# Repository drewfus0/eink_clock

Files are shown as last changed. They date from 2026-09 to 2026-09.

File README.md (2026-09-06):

# ESP32-E E-Paper Smart Clock & Environmental Monitor

<p align="center">
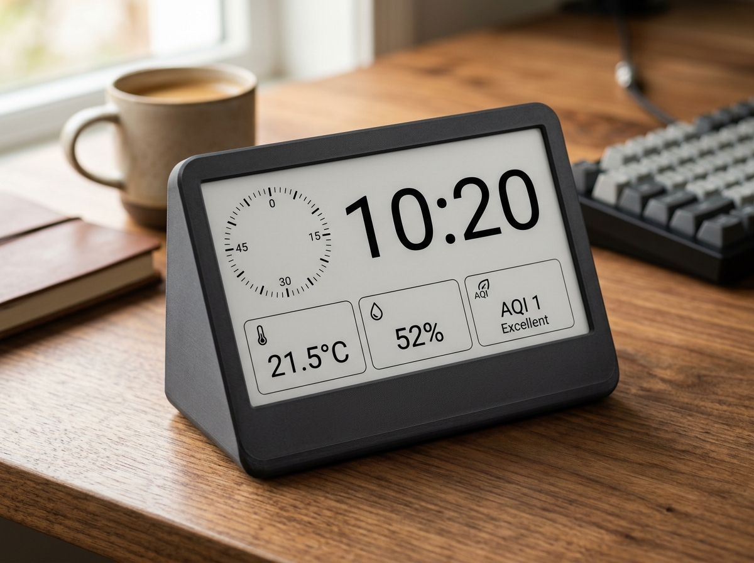
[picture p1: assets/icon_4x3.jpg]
ESP32-E E-Paper Clock
  
</p>

An ultra-low-power, battery-friendly smart desk clock and environmental monitor built with the **DFRobot FireBeetle 2 ESP32-E**, a **Waveshare 7.5" V2 (800x480) E-Paper display**, and an **ENS160 + AHT21 sensor module**.

Features automated **dual-mode Over-The-Air (OTA) updates** (GitHub Releases & local Web Browser), a fast 10-second circular seconds ring with differential refresh, and a custom **3D-printable 70° desk stand enclosure**.

---

## ✨ Features

- **High-Contrast 7.5" E-Paper Display (800x480)**:
  - Giant, crisp time typography and full date display.
  - Animated circular 60-second progress ring with 10-second tick updates.
  - Periodic anti-ghosting full refresh with differential partial updates for minimal power consumption.
- **Precision Environmental Telemetry**:
  - **AHT21**: Ambient temperature (°C / °F) and relative humidity with comfort indicators.
  - **ENS160**: Multi-gas indoor air quality (AQI rating 1–5, TVOC in ppb, equivalent CO₂ in ppm).
- **Dual-Mode OTA Firmware Updates**:
  - **Automated GitHub Releases**: Checks for newer releases via GitHub Releases during periodic 6-hour NTP syncs and flashes in the background.
  - **Local Web Browser Updates**: Interactive web dashboard at `http://<IP>/update` or `http://eink-clock.local/update` with live progress bars.
  - **PlatformIO / ArduinoOTA**: Direct wireless network flashing over port 3232.
- **Power Optimization**:
  - Utilizes ESP32 deep sleep between updates (radio shut down, I2C powered off).
  - Displays battery voltage, percentage, and charging state via ADC characterization.
- **Custom 3D-Printable 70° Desk Stand**:
  - Toolless 6-point snap-fit assembly.
  - Thermally isolated sensor chamber with dedicated ventilation louvers.
  - Direct access port for USB-C charging and programming.

---

## 🛠️ Hardware Stack

| Component | Model / Spec | Interface |
| :--- | :--- | :--- |
| **Microcontroller** | DFRobot FireBeetle 2 ESP32-E (16MB Flash) | — |
| **Display Panel** | Waveshare 7.5" Black/White V2 (800x480) | Hardware SPI (VSPI) |
| **Display Driver** | Waveshare e-Paper Driver HAT (Rev 2.3) | GPIO 13 (PWR latch), CS=14, DC=26, RST=25 |
| **Sensors** | ENS160 + AHT21 Combo Breakout Module | I2C (SDA=21, SCL=22) |
| **Power** | 3.7V LiPo Pouch Cell (1000–2500 mAh) | PH2.0 battery connector |

---

## 🚀 Getting Started

### 1. Build and Flash via PlatformIO
Connect the FireBeetle 2 ESP32-E via USB:
```bash
# Build firmware
pio run

# Upload firmware and monitor serial output
pio run -t upload -t monitor
```

### 2. Creating Releases (Auto-OTA)
To publish a new firmware version to GitHub Releases:
```bash
./create-release.sh
```
The script will auto-increment the patch version, compile the binary, commit, tag, and publish the release via GitHub CLI (`gh`). Any connected clocks will automatically detect and install the update on their next scheduled sync!

### 3. 3D Printable Enclosure
Check out the [`cad/`](cad/) directory for:
- `front_bezel.stl`: Front frame with display viewport and snap slots.
- `rear_stand.stl`: 70° angled desk stand housing.
- `eink_clock_enclosure.scad`: Fully parametric OpenSCAD source file.
- `README.md`: Slicer settings and step-by-step assembly guide.

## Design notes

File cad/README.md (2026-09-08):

# 3D Printable Enclosure - 7.5" E-Paper Desk Clock (70° Tilt)

A two-piece, toolless snap-fit desk stand enclosure tailored for the Waveshare 7.5" V2 E-Paper display, DFRobot FireBeetle 2 ESP32-E, ENS160+AHT21 air quality sensor, and a flat LiPo pouch battery.

---

## 📁 CAD Files in this Directory

| File | Description |
| :--- | :--- |
| [`front_bezel.stl`](front_bezel.stl) | Front frame with active viewing window, glass retention shelf, and snap receivers |
| [`rear_stand.stl`](rear_stand.stl) | Rear housing with integrated 70° desk stand, component bays, USB-C slot, and snap tabs |
| [`eink_clock_enclosure.scad`](eink_clock_enclosure.scad) | Parametric OpenSCAD source file for modifying tolerances or tilt angles |
| [`generate_stl.py`](generate_stl.py) | Standalone Python script to regenerate binary STLs directly |

---

## 🖨️ Recommended 3D Slicer Settings

| Setting | Recommended Value | Notes |
| :--- | :--- | :--- |
| **Material** | **PETG** or **PLA** | PETG is ideal for resilient snap-fit tabs that flex without breaking |
| **Layer Height** | **0.20 mm** | Good balance between surface finish and print speed |
| **Perimeters / Walls** | **3 to 4 walls** | Ensures robust snap tabs and rigid stand structure |
| **Infill** | **15% – 20%** | Gyroid or Cubic pattern |
| **Top / Bottom Layers** | **4 / 4 layers** | Solid finish on flat surfaces |

### Print Orientation & Supports:
1. **`front_bezel.stl`**:
   - Orient **flat face-down** on the build plate (window facing the bed).
   - A textured PEI sheet will give the front bezel a premium matte textured look!
   - **Supports**: **None required** (0% support).
2. **`rear_stand.stl`**:
   - Orient with the flat base on the build plate.
   - **Supports**: Tree supports (organic) enabled only for the small horizontal USB-C cutout bridge.

---

## 🛠️ Step-by-Step Assembly Instructions

### Step 1: Install the Waveshare 7.5" Display
1. Place the front bezel face-down on a soft, clean surface (e.g. microfiber cloth).
2. Drop the Waveshare 7.5" e-Paper panel into the rear stepped recess. The active screen area fits into the viewing window, and the glass edges rest against the inner retention ledge.
3. Pass the bottom flexible flat cable (FPC) through the relief notch.

### Step 2: Mount the Electronics into the Rear Housing
1. **FireBeetle 2 ESP32-E**: Slide the board into the left retention cradle with the USB-C connector facing the side port cutout.
2. **Waveshare e-Paper Driver HAT**: Seat the board on the upper right mounting standoffs and connect the 8-pin JST-PH cable from the HAT to the display FPC adapter.
3. **ENS160 + AHT21 Sensor**: Place the sensor module into the lower-right isolated chamber directly over the ventilation louvers. Run the 4 I2C wires (3.3V, GND, SDA IO21, SCL IO22) to the FireBeetle board.
4. **LiPo Pouch Battery**: Connect the battery lead to the FireBeetle PH2.0 battery port, and rest the battery into the center cavity (can be secured with a small strip of double-sided tape).

### Step 3: Snap Together
1. Align the front bezel with the rear housing.
2. Press gently along the perimeter until the **6 snap-fit latches** click into place (top, bottom, and sides).
3. The clock is now assembled and sits at an ergonomic 70° angle on your desk!

---

## 🔄 Disassembly (Opening the Case)
If you ever need to service the battery or rewire components:
- Insert a small flat tool, guitar pick, or coin into the **pry slot on the bottom center edge**.
- Gently twist to release the bottom snap tabs, then unlatch the top and sides. No screws or destructive force required!

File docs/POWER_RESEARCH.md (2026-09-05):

# Power Management & Display Update Cycle Research

This research document analyzes power consumption, e-paper display refresh dynamics, and battery runtime expectations for the 3000mAh LiPo powered E-Ink Clock.

---

## 1. E-Paper Display Refresh Dynamics (Waveshare 7.5")

### Physical Characteristics of E-Ink
Electrophoretic ink displays work by physically migrating micro-capsules of charged black and white pigments through a viscous fluid using electric fields. Once moved, they remain in place indefinitely without consuming any electricity.

### Refresh Modes:
1. **Full Refresh:**
   - **Duration:** Typically **3.0 to 4.5 seconds** for 7.5-inch panels (800x480).
   - **Visual Effect:** Several high-contrast flashes (inverting black/white) to clear particle memory.
   - **Power Consumption:** ~25mA to 35mA during the active 3.5s cycle.
   - **Panel Health:** Essential to prevent image retention ("ghosting") and irreversible particle burn-in.

2. **Partial Refresh (Fast Mode):**
   - **Duration:** ~0.5 to 0.8 seconds.
   - **Visual Effect:** Only the updated pixels change without flashing the whole screen.
   - **Caveat:** Over multiple consecutive partial updates, minor ghosting accumulates. A periodic full refresh (e.g., every 30 to 60 cycles) is recommended by GoodDisplay & Waveshare.

### Recommended Update Intervals:
- **60 Seconds (1 Minute) - *Current Default*:**
  - Standard clock operation where the minute digit increments seamlessly.
  - Aligned to `:00` seconds of each minute using the ESP32 RTC.
  - Periodic full refresh once every 30 minutes to wipe any ghosting clean.
- **300 Seconds (5 Minutes) - *Extended Battery Mode*:**
  - Ideal for wall-mounted weather and indoor environment stations.
  - Multiplies battery life by ~4.5x.

---

## 2. Power Consumption Breakdown (Fast Partial Refresh)

| Subsystem / State | Current Draw | Typical Duration | Frequency |
|:---|:---|:---|:---|
| **ESP32 Deep Sleep** (low-power jumper cut) | **~15 µA** | ~58 seconds | Continuous |
| **Display Controller Standby** (`powerOff()`) | **~20 µA** | ~58 seconds | Retains internal SRAM for fast differential refresh |
| **Active ESP32 + I2C Sensors** | ~35 mA | 0.2 seconds | Once per minute |
| **Fast Partial Refresh** (7.5" V2 / T7) | ~30 mA | **1.6 seconds** | 29 out of 30 minutes (no screen flashing) |
| **Periodic Full Refresh** (Anti-ghosting) | ~30 mA | **4.2 seconds** | Once every 30 cycles (Cycle #30, #60, ...) |
| **WiFi + NTP Time Sync** | ~110 mA | ~2.5 seconds | **Once every 6 hours** |

### Retaining Controller SRAM Across Deep Sleep
- **`display.hibernate()` (< 1 µA):** Shuts off the display controller completely. Because controller SRAM is lost, every subsequent wake-up must do a slow full refresh (4.2s with heavy black/white inversion flickering).
- **`display.powerOff()` (~20 µA):** Turns off the high-voltage panel driving charge pumps (safe for e-ink particles, zero DC bias), but keeps the Waveshare HAT / GD7965 controller logic powered. This preserves the previous frame buffer, enabling instant, differential **fast partial refresh (1.6s)** without screen flash.
- **Standby Impact:** 20 µA draws only `0.020 mA × 24h = 0.48 mAh/day`. Over 30 days, that is only **14.4 mAh** out of a 3000 mAh battery!

---

## 3. Battery Longevity Projections (3000mAh LiPo)

Assuming an 85% usable battery capacity (**2550 mAh**) to safeguard the LiPo cell from deep discharge:

### Scenario A: Fast Partial Refresh (1-Minute Updates, User Target: 1–2 Weeks)
- **Fast Partial Cycles (29 per 30 mins):**  
  - Active: 1.8s (0.2s sensors + 1.6s display) @ ~32mA = 57.6 mA·s  
  - Sleep: 58.2s @ (15 µA ESP32 + 20 µA display) = 2.04 mA·s  
  - Energy per cycle: **59.64 mA·s**
- **Full Refresh Cycle (1 per 30 mins):**  
  - Active: 4.4s (0.2s sensors + 4.2s display) @ ~32mA = 140.8 mA·s  
  - Sleep: 55.6s @ 35 µA = 1.95 mA·s  
  - Energy per cycle: **142.75 mA·s**
- **WiFi NTP Sync (every 6 hours = once per 360 cycles):**  
  - Extra Active: 2.5s @ 110mA = 275 mA·s (~0.76 mA·s per cycle)
- **Average 30-minute block consumption:**  
  `[ (29 × 59.64) + 142.75 + (0.76 × 30) ] = 1729.56 + 142.75 + 22.8 = 1895.1 mA·s`  
  Average current: `1895.1 mA·s / 1800 s ≈ 1.05 mA`
- **Expected Battery Life:**  
  `2550 mAh / 1.05 mA ≈ 2,428 hours` ≈ **~101 days (~3.3 months)** on a single charge!  
  *(Drastically exceeds the user's 1–2 week requirement by 7x, with instant flicker-free updates).*

### Scenario B: 5-Minute Update Interval (Maximum Longevity Mode)
- **Active Cycle:** 1.8s @ 32mA = 57.6 mA·s
- **Sleep Cycle:** 298.2s @ 0.035mA = 10.4 mA·s
- **Average Current:** `(57.6 + 10.4) / 300 ≈ 0.23 mA`
- **Expected Battery Life:**  
  `2550 mAh / 0.23 mA ≈ 11,086 hours` ≈ **~460 days (~1.25 years)** on a single charge!

---

## 4. Hardware Power Saving Recommendations
1. **Low Power Jumper:** Cut the "Low Power" solder jumper pad on the FireBeetle 2 ESP32-E board to disable the always-on power LED and unused USB UART circuitry.
2. **Display Power Mode:** Use `displayPowerOff()` (configured in `src/main.cpp`) to turn off high-voltage rail drivers while preserving controller SRAM.
3. **Anti-Ghosting Interval:** Configured via `FULL_REFRESH_CYCLE_COUNT` in `include/config.h` (default: 30 cycles / 30 minutes).
4. **Sensor Sleep:** The ENS160 enters idle mode between measurements.

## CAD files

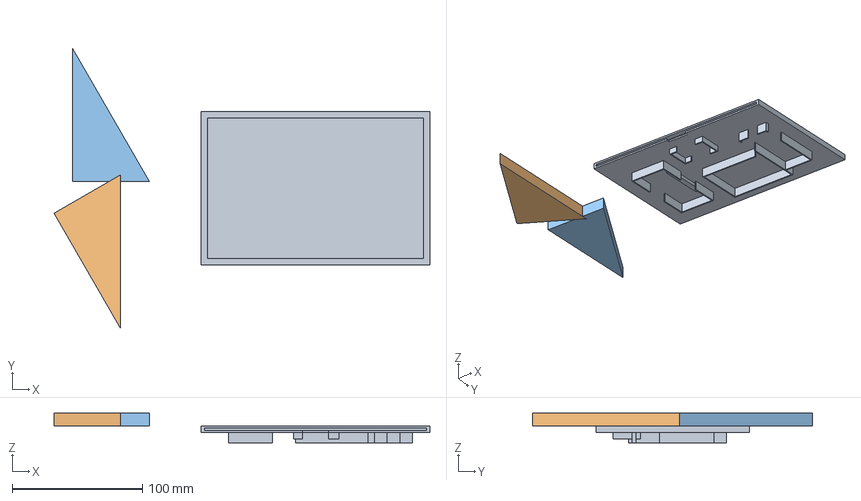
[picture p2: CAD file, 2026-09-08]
cad/Front Panel.FCStd
289.2 x 215.1 x 23.0 mm

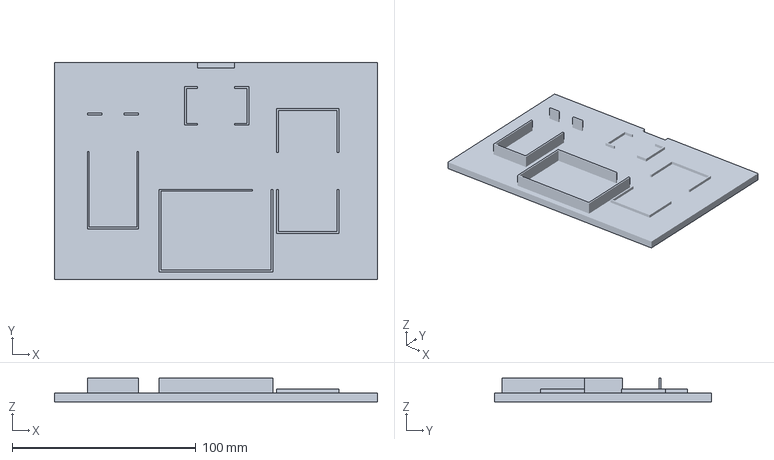
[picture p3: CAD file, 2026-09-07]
cad/Front Panel-BodyPocket011.3mf
176.0 x 118.0 x 13.0 mm

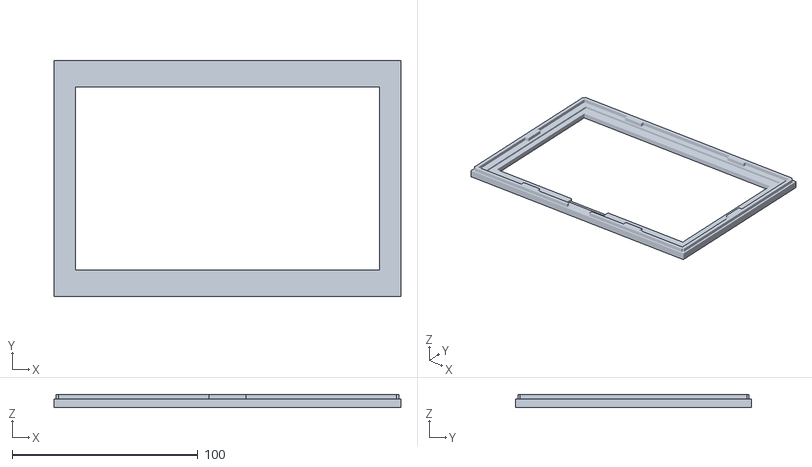
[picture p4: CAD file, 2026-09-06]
cad/front_bezel.stl
187.0 x 127.0 x 7.20

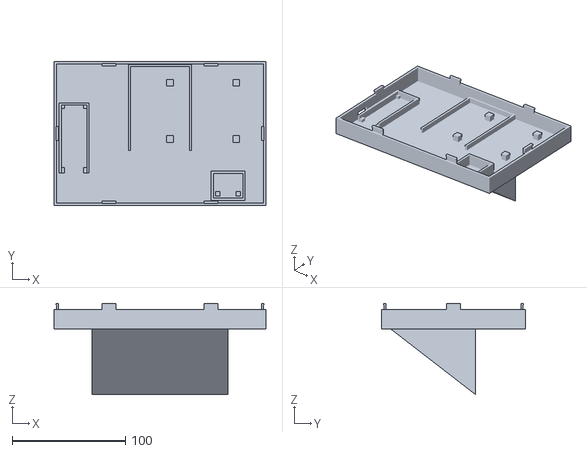
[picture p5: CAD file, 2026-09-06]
cad/rear_stand.stl
187.0 x 127.0 x 80.5

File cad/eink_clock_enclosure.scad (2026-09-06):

// =============================================================================
// 7.5" E-PAPER DESK CLOCK ENCLOSURE (70° TILT ANGLE)
// Parametric 3D Printable Enclosure with Snap-Fit Latches
// =============================================================================
// Designed for:
//   - Waveshare 7.5" V2 E-Paper Display (800x480)
//   - DFRobot FireBeetle 2 ESP32-E (USB-C)
//   - Waveshare e-Paper Driver HAT (Rev 2.3)
//   - ENS160 + AHT21 Air Quality & Temp/Humidity Sensor Module
//   - Flat LiPo Pouch Battery (1000mAh - 2500mAh)
// =============================================================================

/* [Render Selection] */
// Which part to render
part = "assembly"; // [assembly: Complete Preview, front: Front Bezel (Print Orientation), rear: Rear Stand (Print Orientation), exploded: Exploded View]

/* [Enclosure Dimensions] */
wall_thick        = 2.4;   // Outer shell wall thickness (mm)
bezel_margin      = 6.0;   // Margin around glass panel (mm)
corner_radius     = 6.0;   // Outer corner rounding radius (mm)
tilt_angle        = 70;    // Desktop viewing angle from horizontal (deg)

/* [Display Specifications (Waveshare 7.5" V2)] */
panel_w           = 170.2; // Glass panel width (mm)
panel_h           = 111.0; // Glass panel height (mm)
panel_t           = 1.35;  // Glass panel thickness with foam backing (mm)
active_w          = 163.2; // Viewable screen width (mm)
active_h          = 97.92; // Viewable screen height (mm)
active_y_offset   = 3.2;   // Offset of active area from center (mm)
fpc_w             = 28.0;  // Ribbon cable width (mm)
fpc_t             = 2.0;   // Ribbon cable relief depth (mm)

/* [Component Dimensions] */
firebeetle_w      = 25.8;  // FireBeetle 2 width (mm)
firebeetle_l      = 60.5;  // FireBeetle 2 length (mm)
firebeetle_t      = 7.5;   // FireBeetle 2 thickness with headers (mm)

hat_w             = 65.5;  // Waveshare HAT width (mm)
hat_l             = 56.5;  // Waveshare HAT length (mm)
hat_t             = 9.0;   // Waveshare HAT thickness (mm)

battery_w         = 55.0;  // LiPo pouch bay width (mm)
battery_l         = 75.0;  // LiPo pouch bay length (mm)
battery_d         = 9.0;   // LiPo pouch bay depth (mm)

sensor_w          = 16.0;  // ENS160+AHT21 width (mm)
sensor_l          = 21.0;  // ENS160+AHT21 length (mm)

/* [Snap-Fit Latch Geometry] */
snap_w            = 12.0;  // Width of each cantilever tab (mm)
snap_t            = 1.5;   // Tab thickness (mm)
snap_h            = 6.5;   // Tab cantilever height (mm)
snap_catch        = 0.75;  // Latch overhang undercut (mm)
joint_clearance   = 0.25;  // Fit tolerance between front and rear (mm)

// Calculated overall dimensions
outer_w = panel_w + (bezel_margin + wall_thick) * 2; // ~187 mm
outer_h = panel_h + (bezel_margin + wall_thick) * 2; // ~128 mm
stand_depth = 65.0; // Depth of desktop wedge foot for stability

$fn = 48;

// =============================================================================
// Top-Level Part Selector
// =============================================================================
if (part == "assembly") {
    // Show assembled model in standing orientation
    rotate([90 - tilt_angle, 0, 0]) {
        color([0.2, 0.2, 0.25]) front_bezel();
        color([0.85, 0.85, 0.9]) translate([0, 0, -18]) rear_housing();
        
        // Ghost display panel in place
        %translate([0, 0, -wall_thick - panel_t/2])
            cube([panel_w, panel_h, panel_t], center=true);
    }
} else if (part == "exploded") {
    rotate([90 - tilt_angle, 0, 0]) {
        color([0.2, 0.2, 0.25]) front_bezel();
        color([0.85, 0.85, 0.9]) translate([0, 0, -45]) rear_housing();
        
        // Display floating between parts
        color([0.95, 0.95, 0.95, 0.8]) translate([0, 0, -22])
            cube([panel_w, panel_h, panel_t], center=true);
    }
} else if (part == "front") {
    // Flat on build plate for printing without supports
    front_bezel();
} else if (part == "rear") {
    // Flat base on build plate for printing
    rotate([0, 0, 0]) rear_housing();
}

// =============================================================================
// Helper Module: Rounded Box
// =============================================================================
module rounded_box(w, h, d, r) {
    hull() {
        translate([-w/2 + r, -h/2 + r, 0]) cylinder(r=r, h=d);
        translate([ w/2 - r, -h/2 + r, 0]) cylinder(r=r, h=d);
        translate([-w/2 + r,  h/2 - r, 0]) cylinder(r=r, h=d);
        translate([ w/2 - r,  h/2 - r, 0]) cylinder(r=r, h=d);
    }
}

// =============================================================================
// 1. FRONT BEZEL
// =============================================================================
module front_bezel() {
    bezel_depth = wall_thick + panel_t + 1.2;

    difference() {
        union() {
            // Main outer rounded bezel body
            rounded_box(outer_w, outer_h, bezel_depth, corner_radius);

            // Perimeter mating rim that inserts into rear case
            translate([0, 0, bezel_depth])
                difference() {
                    rounded_box(outer_w - wall_thick*2 - joint_clearance*2, 
                                outer_h - wall_thick*2 - joint_clearance*2, 
                                3.5, corner_radius - wall_thick);
                    translate([0, 0, -0.1])
                        rounded_box(outer_w - wall_thick*4, outer_h - wall_thick*4, 4.0, 2);
                }
        }

        // 1. Active viewport window with aesthetic 45° chamfer
        translate([0, active_y_offset, -0.5]) {
            // Cutout through face
            cube([active_w, active_h, bezel_depth + 1], center=true);
            
            // Front chamfer
            hull() {
                translate([0, 0, -0.1])
                    cube([active_w + 3.0, active_h + 3.0, 0.1], center=true);
                translate([0, 0, 1.8])
                    cube([active_w, active_h, 0.1], center=true);
            }
        }

        // 2. Stepped recess for glass panel (0.3mm tolerance around glass)
        translate([0, 0, wall_thick])
            cube([panel_w + 0.6, panel_h + 0.6, panel_t + 10], center=true);

        // 3. FPC Ribbon cable clearance notch at bottom
        translate([0, -panel_h/2 - 2, wall_thick])
            cube([fpc_w + 4, 16, fpc_t + 4], center=true);

        // 4. Female snap-fit receiver slots (6 perimeter catches)
        snap_positions = [
            [-outer_w/4,  outer_h/2 - wall_thick - 1.0], // Top Left
            [ outer_w/4,  outer_h/2 - wall_thick - 1.0], // Top Right
            [-outer_w/4, -outer_h/2 + wall_thick + 1.0], // Bottom Left
            [ outer_w/4, -outer_h/2 + wall_thick + 1.0], // Bottom Right
            [-outer_w/2 + wall_thick + 1.0, 0],          // Side Left
            [ outer_w/2 - wall_thick - 1.0, 0]           // Side Right
        ];

        for (p = snap_positions) {
            translate([p[0], p[1], bezel_depth + 1.2]) {
                if (abs(p[0]) > outer_w/3) {
                    // Side slots
                    cube([snap_t*2 + 1.0, snap_w + 1.0, 3.2], center=true);
                } else {
                    // Top/Bottom slots
                    cube([snap_w + 1.0, snap_t*2 + 1.0, 3.2], center=true);
                }
            }
        }

        // 5. Coin pry notch on bottom edge for easy disassembly
        translate([0, -outer_h/2, 0])
            cube([18, 3.0, 2.0], center=true);
    }

    // Corner alignment pins
    for (cx = [-panel_w/2 - 1.5, panel_w/2 + 1.5]) {
        for (cy = [-panel_h/2 - 1.5, panel_h/2 + 1.5]) {
            translate([cx, cy, wall_thick])
                cylinder(r=1.5, h=panel_t + 1.0);
        }
    }
}

// =============================================================================
// 2. REAR DESK STAND HOUSING
// =============================================================================
module rear_housing() {
    base_depth = 16.0; // Main chassis depth
    
    difference() {
        union() {
            // Main housing body
            rounded_box(outer_w, outer_h, base_depth, corner_radius);

            // Integrated 70° Desktop Wedge Stand
            stand_h = outer_h * 0.75;
            stand_w = outer_w * 0.65;
            
            translate([0, -outer_h/2 + stand_h/2 + 6, base_depth]) {
                hull() {
                    // Top of wedge (tapered)
                    translate([0, stand_h/2 - 10, 0])
                        rounded_box(stand_w * 0.7, 12, 1.0, 4);
                    // Bottom footing of wedge (wide desktop contact surface)
                    translate([0, -stand_h/2 + 6, stand_depth * cos(90 - tilt_angle)])
                        rounded_box(stand_w, 20, 3.0, 6);
                    // Base junction
                    translate([0, -stand_h/2 + 6, 0])
                        rounded_box(stand_w, 20, 1.0, 6);
                }
            }
        }
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

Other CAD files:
cad/Front Panel.3mf

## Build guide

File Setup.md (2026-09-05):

Hardware list
- FireBeetle 2 ESP32-E(N16R2)
- Waveshare e-Paper Driver HAT (Rev 2.3)
- Waveshare 7.5inch e-Paper (V2 / 800x480)
- ENS160+AHT21 Air Quality Sensor Module 
- Battery 3.7 lipo 3.7v 11.1Wh 3000mah

Simple Project Breif.
This is a clock using the ESP32-E, it should sync to the internet and display the time and date. It should also display the temperature and humidity from the AHT21 sensor and air quality from the ENS160 sensor. All should be displayed on the e-paper screen.
Display Priority:
1. Time.
2. Date.
3. Temperature.
4. Humidity.
5. Air Quality.
6. Battery/other info.

The code should be in platformIO. 
Power Management:
 The device should sleep most of the time to save power. Interval to be research display update cycle for display and power usage.
Display:
The display is a 7.5inch e-Paper (800x480) and uses a Waveshare e-Paper Driver HAT (Rev 2.3).
Sensors:
The sensors are connected to the ESP32-E via the I2C bus.
Connectivity & Updates:
The ESP32-E has WiFi for connecting to the internet for NTP time synchronization and Over-The-Air (OTA) firmware updates.

OTA Firmware Updates:
1. Dual-slot partition table (partitions_16MB_ota.csv) with 6.25MB app0/app1 slots.
2. Automated GitHub Releases Updates:
   - Repository: https://github.com/drewfus0/eink_clock
   - Every 6 hours during NTP sync (or on boot/reset), the clock checks version.json on GitHub.
   - If a new version is detected, it automatically downloads firmware.bin from the GitHub Release, renders an updating dialog on the e-paper panel, flashes into the alternate slot, and reboots.
   - Use `./create-release.sh` to auto-bump the version and build release binaries.
   - GitHub Actions (.github/workflows/release.yml) automatically compiles and attaches firmware.bin whenever a git tag (e.g. `v1.0.1`) is pushed.
3. Web Browser Upload: http://<IP>/update or http://eink-clock.local/update.
4. PlatformIO CLI Upload: pio run -e firebeetle2_esp32e_ota -t upload.
5. Deep-Sleep Integration:
   - On cold boot or reset button press, a 30-second local update window opens.
   - During normal unattended 6-hour syncs, Wi-Fi stays on for only ~2.3 seconds to sync NTP and check GitHub, preserving battery longevity.

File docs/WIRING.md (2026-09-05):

# Hardware Wiring & Pinout Guide

This guide details the exact electrical connections between the **DFRobot FireBeetle 2 ESP32-E (DFR1139/DFR0654)**, the **Waveshare e-Paper Driver HAT (Rev 2.3)**, the **Waveshare 7.5-inch e-Paper display (V2 / 800x480)**, and the **ENS160+AHT21** environmental sensor module.

---

## 1. Waveshare e-Paper Driver HAT (Rev 2.3) to FireBeetle 2 ESP32-E (SPI)

The Waveshare e-Paper Driver HAT Rev 2.3 is the official driver board designed specifically for Waveshare 7.5-inch e-Paper panels.

### Onboard Slide Switches:
- **Display Config Switch:** Set to **`B`** (7.5-inch series).
- **Interface Config Switch:** Set to **`0`** (4-line SPI).

### Pin Connections to FireBeetle 2 ESP32-E:
| Waveshare HAT Pin | Wire Color (Standard 8-pin) | FireBeetle 2 Silkscreen | ESP32 GPIO | Function | Critical Notes |
|:---|:---|:---|:---|:---|:---|
| **VCC** | Red | **3V3** | 3.3V | Power Supply | 3.3V logic & panel supply |
| **GND** | Black | **GND** | GND | Ground | Common Ground |
| **DIN** | Blue | **23/MOSI** | GPIO 23 | SPI MOSI | Master Out Slave In |
| **CLK** | Yellow | **18/SCK** | GPIO 18 | SPI Clock | SPI Bus Clock |
| **CS** | Orange | **14/D6** | GPIO 14 | SPI CS | Chip Select (Active LOW) |
| **DC** | Green | **26/D3** | GPIO 26 | Data/Command | HIGH = Data, LOW = Command |
| **RST** | White | **25/D2** | GPIO 25 | Reset | Active LOW reset pulse |
| **BUSY** | Purple | **4/D12** | GPIO 4 | Busy Status | Hardware status pin |
| **PWR** | Grey (if 9-pin) | **13/D7** (or **3V3**) | GPIO 13 | **Power Control** | Connect to `13/D7` (or directly to `3V3`). |

> [!TIP]
> **Why `PWR` is kept powered across deep sleep:**
> E-paper partial refresh relies on the controller chip's internal SRAM to compare the previous frame against the new frame. Keeping `PWR` at 3.3V during sleep (or having GPIO 13 hold HIGH) preserves the controller SRAM so partial updates render dark and sharp with zero spottiness. Standby current in this state is only ~2 to 5 µA!

---

## 2. ENS160 + AHT21 Sensor Module to FireBeetle 2 ESP32-E (I2C)

The combined ENS160 (Air Quality: AQI, eCO2, TVOC) and AHT21 (Temperature & Relative Humidity) module communicates over a single shared I2C bus.

| Sensor Pin | Wire Color (Suggested) | FireBeetle 2 PCB Silkscreen | ESP32 GPIO | Function | Notes |
|:---|:---|:---|:---|:---|:---|
| **VCC** | Black | **3V3** | 3.3V Rail | Power Supply | 3.3V operation |
| **GND** | White | **GND** | Ground | Common Ground | Ground |
| **SDA** | Purple | **SDA** | GPIO 21 | I2C Data Line | 0x38 (AHT21), 0x53 or 0x52 (ENS160) |
| **SCL** | Grey | **SCL** | GPIO 22 | I2C Clock Line | 100 kHz standard clock |

*Both sensors reside on the same two I2C wires. The firmware automatically detects the ENS160 on either 0x53 or 0x52, and AHT21 on 0x38.*

---

## 3. Battery & Power Connection

- **Battery:** 3.7V LiPo rechargeable battery (3000mAh, 11.1Wh).
- **Connector:** Connect the battery JST-PH 2.0mm lead directly to the onboard **BAT** connector on the FireBeetle 2 ESP32-E.
- **Charging:** When a USB Type-C cable is connected, the onboard charging IC will charge the LiPo safely at up to 500mA/1000mA with LED charge status.
- **Voltage Sensing:** The FireBeetle 2 ESP32-E includes an integrated 1MΩ / 1MΩ voltage divider already wired directly to **GPIO 34** (ADC1_CH6). No external resistors or extra wiring are needed!

---

## 2. ENS160 + AHT21 Sensor Module to FireBeetle 2 ESP32-E (I2C)

The combined ENS160 (Air Quality: AQI, eCO2, TVOC) and AHT21 (Temperature & Relative Humidity) module communicates over a single shared I2C bus.

| Sensor Pin | Wire Color (Suggested) | FireBeetle 2 PCB Silkscreen | ESP32 GPIO | Function | Notes |
|:---|:---|:---|:---|:---|:---|
| **VCC** | Black | **3V3** | 3.3V Rail | Power Supply | 3.3V operation |
| **GND** | White | **GND** | Ground | Common Ground | Ground |
| **SDA** | Purple | **SDA** | GPIO 21 | I2C Data Line | 0x38 (AHT21), 0x53 or 0x52 (ENS160) |
| **SCL** | Grey | **SCL** | GPIO 22 | I2C Clock Line | 100 kHz standard clock |

*Both sensors reside on the same two I2C wires. The firmware automatically detects the ENS160 on either 0x53 or 0x52, and AHT21 on 0x38.*

---

## 3. Battery & Power Connection

- **Battery:** 3.7V LiPo rechargeable battery (3000mAh, 11.1Wh).
- **Connector:** Connect the battery JST-PH 2.0mm lead directly to the onboard **BAT** connector on the FireBeetle 2 ESP32-E.
- **Charging:** When a USB Type-C cable is connected, the onboard charging IC will charge the LiPo safely at up to 500mA/1000mA with LED charge status.
- **Voltage Sensing:** The FireBeetle 2 ESP32-E includes an integrated 1MΩ / 1MΩ voltage divider already wired directly to **GPIO 34** (ADC1_CH6). No external resistors or extra wiring are needed!

---

## 4. FireBeetle 2 Ultra-Low Power Optimization

The FireBeetle 2 ESP32-E has a dedicated low-power solder pad on the bottom/top of the board:
- By default, the power LED remains lit during deep sleep, consuming ~1.5mA.
- Cutting or desoldering the **Low Power / LED jumper** (marked on the PCB) disconnects the standby LED and peripheral LDO, dropping deep sleep current down to **~10 to 15 µA**!

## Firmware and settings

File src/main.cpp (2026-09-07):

#include <Arduino.h>
#include <esp_sleep.h>
#include <WiFi.h>
#include "config.h"
#include "display_config.h"
#include "sensors.h"
#include "battery.h"
#include "time_sync.h"
#include "ota_manager.h"
#include "ui.h"

// Variables preserved in ESP32 RTC Slow Memory across deep sleep
RTC_DATA_ATTR static uint32_t bootCount = 0;
RTC_DATA_ATTR static time_t lastNtpSyncEpoch = 0;
RTC_DATA_ATTR static float rtcNtpDiffSec = 0.0f;
RTC_DATA_ATTR static bool rtcHasNtpDiff = false;

void setup() {
    Serial.begin(115200);
    delay(100);
    bootCount++;

    log_i("=================================================");
    log_i("ESP32-E E-Paper Clock Starting. Boot Count: %u", bootCount);
    log_i("=================================================");

    initTimezone();
    initBattery();

    // Check if NTP time sync is required:
    // 1. First boot / invalid RTC time
    // 2. Interval exceeded (NTP_SYNC_INTERVAL_HOURS)
    time_t currentEpoch = time(nullptr);
    bool needNtpSync = false;

    if (lastNtpSyncEpoch == 0 || currentEpoch < 1600000000) {
        needNtpSync = true;
    } else if ((currentEpoch - lastNtpSyncEpoch) >= (NTP_SYNC_INTERVAL_HOURS * 3600)) {
        needNtpSync = true;
    }

    // Local OTA window (WebServer / ArduinoOTA) is opened on initial boot (or button reset)
    bool openLocalOta = (bootCount <= 1);

    bool ntpSuccess = false;
    if (needNtpSync) {
        log_i("Initiating scheduled NTP synchronization...");
        // Keep Wi-Fi connected to check GitHub releases and optionally open local OTA
        ntpSuccess = syncNtpTime(true);
        if (ntpSuccess) {
            lastNtpSyncEpoch = time(nullptr);
            if (hasLastNtpDiff()) {
                rtcNtpDiffSec = getLastNtpDiffSec();
                rtcHasNtpDiff = true;
            }
        }

        // Check for GitHub Release OTA update while Wi-Fi is already active
        if (WiFi.status() == WL_CONNECTED) {
            checkAndApplyGithubOta();
        }

        // If local OTA window is not needed, shut down Wi-Fi immediately to conserve battery
        if (!openLocalOta) {
            disconnectWiFi();
        }
    } else {
        log_i("Skipping WiFi/NTP sync (next sync in %ld sec)", 
              (long)((lastNtpSyncEpoch + (NTP_SYNC_INTERVAL_HOURS * 3600)) - currentEpoch));
    }

    // Fetch RTC time
    TimeInfo timeInfo = getCurrentTimeInfo();

    // Determine refresh mode: Full anti-ghosting refresh on boot or every FULL_REFRESH_CYCLE_COUNT
    bool fullRefresh = (bootCount <= 1) || ((bootCount % FULL_REFRESH_CYCLE_COUNT) == 0);

    // Full dashboard update on boot or on minute rollover (:00 to :09)
    bool isMinuteRollover = (bootCount <= 1) || (timeInfo.seconds < 10);

    uint32_t tStart = millis();

    if (isMinuteRollover || fullRefresh) {
        // Full dashboard update: Read sensors and redraw the entire screen
        initSensors();
        displayInitHardware(fullRefresh);

        SensorData sensorData = readSensors();
        BatteryInfo batteryInfo = readBattery();

        SystemState sysState;
        sysState.bootCount = bootCount;
        sysState.lastNtpSyncEpoch = lastNtpSyncEpoch;
        sysState.ntpJustSynced = ntpSuccess;
        sysState.updateIntervalSec = DISPLAY_UPDATE_INTERVAL_SEC;
        sysState.lastNtpDiffSec = rtcNtpDiffSec;
        sysState.hasNtpDiff = rtcHasNtpDiff;

        // Calculate time remaining until next scheduled NTP synchronization
        time_t nowEpoch = time(nullptr);
        int32_t secToNext = 0;
        if (lastNtpSyncEpoch > 0 && nowEpoch >= lastNtpSyncEpoch) {
            int32_t elapsedSinceSync = (int32_t)(nowEpoch - lastNtpSyncEpoch);
            secToNext = (int32_t)(NTP_SYNC_INTERVAL_HOURS * 3600) - elapsedSinceSync;
            if (secToNext < 0) secToNext = 0;
        } else {
            secToNext = (int32_t)(NTP_SYNC_INTERVAL_HOURS * 3600);
        }
        sysState.secToNextNtp = secToNext;

        if (openLocalOta && WiFi.status() == WL_CONNECTED) {
            snprintf(sysState.otaUrl, sizeof(sysState.otaUrl), "http://%s/update", WiFi.localIP().toString().c_str());
        }

        log_i("Pin states: BUSY(IO%d)=%d, RST(IO%d)=%d, CS(IO%d)=%d", 
              EPD_BUSY_PIN, (EPD_BUSY_PIN >= 0) ? digitalRead(EPD_BUSY_PIN) : -1,
              EPD_RST_PIN, digitalRead(EPD_RST_PIN),
              EPD_CS_PIN, digitalRead(EPD_CS_PIN));

        log_i("Updating full dashboard (Full: %s, Boot: %u, Sec: :%02d)...", 
              fullRefresh ? "YES" : "NO", bootCount, timeInfo.seconds);
        renderDashboard(timeInfo, sensorData, batteryInfo, sysState, fullRefresh);
    } else {
        // Intermediate 10-second tick (:10, :20, :30, :40, :50):
        // Skip I2C sensor bus and update only the circular seconds window!
        displayInitHardware(false);

        log_i("Updating seconds ring only (Sec: :%02d, Boot: %u)...", timeInfo.seconds, bootCount);
        renderSecondsTickOnly(timeInfo.seconds);
    }

    uint32_t tElapsed = millis() - tStart;
    log_i("Display refresh call completed in %u ms", tElapsed);
    
    // Safety delay only if the driver returned prematurely (< 500ms)
    if (tElapsed < 500) {
        log_w("Display refresh returned prematurely (%u ms). Waiting 5s for physical waveform...", tElapsed);
        delay(5000);
    }

    // Power off panel driving voltages (charges turned off, but controller SRAM retained for fast differential refresh)
    log_i("Powering off display driver voltages...");
    displayPowerOff();

    // If an OTA listening window is scheduled, open it now
    if (openLocalOta && WiFi.status() == WL_CONNECTED) {
        runOtaWindow(OTA_WINDOW_TIMEOUT_SEC);
    }

    // Calculate sleep duration synchronized to the exact next 10-second boundary
    uint64_t sleepSeconds = DISPLAY_UPDATE_INTERVAL_SEC;
    time_t now = time(nullptr);
    struct tm tm_now;
    localtime_r(&now, &tm_now);
    if (timeInfo.isValid || tm_now.tm_year > (2020 - 1900)) {
        int secRemaining = 10 - (tm_now.tm_sec % 10);
        if (secRemaining <= 0) secRemaining = 10;
        sleepSeconds = secRemaining;
    }

    log_i("Entering ESP32 deep sleep for %llu seconds...", sleepSeconds);
    Serial.flush();

    esp_sleep_enable_timer_wakeup(sleepSeconds * 1000000ULL);
    esp_deep_sleep_start();
}

void loop() {
    // Execution will never reach loop() due to deep sleep
}

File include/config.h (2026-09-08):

#pragma once

#include <Arduino.h>

// =============================================================================
// Wi-Fi & NTP Configuration
// =============================================================================
// Replace with your local Wi-Fi credentials
#define WIFI_SSID           "ImWifiRick"
#define WIFI_PASSWORD       "1234567890"
#define WIFI_TIMEOUT_MS     15000 // 15 seconds max connection attempt

// NTP Time server configuration
#define NTP_SERVER_1        "pool.ntp.org"
#define NTP_SERVER_2        "time.nist.gov"

// Timezone definition (POSIX format allows automatic Daylight Saving Time)
// Examples:
// Sydney / Melbourne:  "AEST-10AEDT,M10.1.0,M4.1.0/3"
// New York (Eastern):  "EST5EDT,M3.2.0,M11.1.0"
// Los Angeles (Pacific):"PST8PDT,M3.2.0,M11.1.0"
// London (GMT/BST):    "GMT0BST,M3.5.0/1,M10.5.0"
// UTC:                 "UTC0"
#define TIMEZONE_POSIX      "AEST-10AEDT,M10.1.0,M4.1.0/3"

// =============================================================================
// Power & Refresh Intervals
// =============================================================================
// Interval between display updates (in seconds).
// 10 seconds for the animated circular seconds progress ring
#define DISPLAY_UPDATE_INTERVAL_SEC   10

// Sync time from NTP periodically instead of every wake-up to conserve battery.
// 6 hours = 21600 seconds.
#define NTP_SYNC_INTERVAL_HOURS       6

// Periodic full refresh to eliminate e-paper ghosting (every 10 minutes = 60 x 10s cycles)
#define FULL_REFRESH_CYCLE_COUNT      60

// =============================================================================
// Firmware Version & Over-The-Air (OTA) Configuration
// =============================================================================
#define FIRMWARE_VERSION              "1.0.12"

// Duration (in seconds) the clock listens for local wireless updates on boot / reset
#define OTA_WINDOW_TIMEOUT_SEC        30
#define OTA_HOSTNAME                  "eink-clock"
#define OTA_PORT                      3232

// GitHub Releases Auto-Update Configuration
#define GITHUB_REPO_OWNER             "drewfus0"
#define GITHUB_REPO_NAME              "eink_clock"
#define GITHUB_VERSION_URL            "https://raw.githubusercontent.com/drewfus0/eink_clock/main/version.json"
#define GITHUB_FIRMWARE_URL           "https://github.com/drewfus0/eink_clock/releases/latest/download/firmware.bin"

// =============================================================================
// Hardware Pin Definitions (FireBeetle 2 ESP32-E)
// =============================================================================
// Waveshare e-Paper Driver HAT (Rev 2.3) to ESP32-E (Hardware VSPI)
#define EPD_BUSY_PIN        -1  // Software timed (-1): guarantees full 4.2s refresh without premature busy-pin cutoff
#define EPD_RST_PIN         25  // Silkscreen: "25/D2"  - Display Hardware Reset
#define EPD_DC_PIN          26  // Silkscreen: "26/D3"  - Data / Command Selection
#define EPD_CS_PIN          14  // Silkscreen: "14/D6"  - SPI Chip Select
#define EPD_SCK_PIN         18  // Silkscreen: "18/SCK" - Hardware SPI Clock
#define EPD_MOSI_PIN        23  // Silkscreen: "23/MOSI"- Hardware SPI MOSI (DIN / SDI)
#define EPD_PWR_PIN         13  // Silkscreen: "13/D7"  - Waveshare HAT Rev 2.3 PWR pin (controls power MOSFET)

// I2C Pins for ENS160 + AHT21 sensor module
#define I2C_SDA_PIN         21  // Silkscreen: "SDA"
#define I2C_SCL_PIN         22  // Silkscreen: "SCL"
#define I2C_FREQ_HZ         100000 // 100 kHz standard mode

// Battery Voltage Sensing
// FireBeetle 2 ESP32-E has an onboard 1M/1M divider connected to GPIO 34 (A4)
#define BATTERY_ADC_PIN     34
#define BATTERY_DIVIDER_RATIO 2.0f // 1M + 1M divider
#define BATTERY_MIN_V       3.20f  // Fully drained LiPo safe cutoff
#define BATTERY_MAX_V       4.20f  // Fully charged LiPo

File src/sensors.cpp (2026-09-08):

#include "sensors.h"
#include "config.h"
#include <Wire.h>
#include <Adafruit_AHTX0.h>
#include <ScioSense_ENS16x.h>
#include <esp_sleep.h>

static Adafruit_AHTX0 aht;
static ENS160 ens160;
static bool ahtInitialized = false;
static bool ensInitialized = false;
static uint8_t ens160Address = 0x53; // Default ENS160 address (can also be 0x52)

// Variables preserved in ESP32 RTC Slow Memory across deep sleep
RTC_DATA_ATTR static bool rtcHasEverWarmedUp = false;
RTC_DATA_ATTR static uint16_t rtcLastValidEco2 = 400;
RTC_DATA_ATTR static uint16_t rtcLastValidTvoc = 0;
RTC_DATA_ATTR static uint8_t rtcLastValidAqi = 1;
RTC_DATA_ATTR static uint8_t rtcStaleMinutes = 0;

bool initSensors() {
    log_i("Initializing I2C bus on SDA=%d, SCL=%d...", I2C_SDA_PIN, I2C_SCL_PIN);
    Wire.begin(I2C_SDA_PIN, I2C_SCL_PIN, I2C_FREQ_HZ);
    delay(50);

    // Initialize AHT21 (typically 0x38)
    if (!ahtInitialized) {
        if (aht.begin(&Wire)) {
            ahtInitialized = true;
            log_i("AHT21 sensor detected and initialized at 0x38");
        } else {
            log_e("Failed to initialize AHT21 sensor at 0x38!");
        }
    }

    // Detect ENS160 without resetting it if already running!
    // We check I2C addresses 0x53 (default) and 0x52.
    uint8_t detectedAddr = 0;
    const uint8_t testAddrs[] = {0x53, 0x52};

    for (uint8_t addr : testAddrs) {
        ens160.begin(&Wire, addr);
        uint8_t partIdBuf[2] = {0};
        if (ens160.read(ENS16X_REGISTER_ADDRESS_PART_ID, partIdBuf, 2) == RESULT_OK) {
            uint16_t id = (partIdBuf[1] << 8) | partIdBuf[0];
            if (id == 0x0160) {
                detectedAddr = addr;
                ens160.partId = id;
                break;
            }
        }
    }

    if (detectedAddr != 0) {
        ensInitialized = true;
        ens160Address = detectedAddr;

        // Inspect current operating mode & device status from registers
        uint8_t opMode = 0xFF;
        bool readOpOk = (ens160.read(ENS16X_REGISTER_ADDRESS_OPMODE, &opMode, 1) == RESULT_OK);
        uint8_t devStatus = 0;
        ens160.read(ENS16X_REGISTER_ADDRESS_DEVICE_STATUS, &devStatus, 1);
        uint8_t validity = (devStatus >> 2) & 0x03;
        bool isRunning = (devStatus & ENS16X_DEVICE_STATUS_ACTIVE) != 0 && (devStatus & ENS16X_DEVICE_STATUS_ERROR) == 0;

        if (readOpOk && isRunning && (opMode == ENS16X_OPERATING_MODE_STANDARD)) {
            log_i("ENS160 at 0x%02X is ACTUALLY RUNNING (OPMODE=0x%02X, Status=0x%02X, Validity=%u). Preserving continuous measurement state!",
                  detectedAddr, opMode, devStatus, validity);
        } else {
            log_i("ENS160 at 0x%02X not actively running (OPMODE=0x%02X, Status=0x%02X, STATAS=%d). Starting standard measurement mode...",
                  detectedAddr, opMode, devStatus, isRunning ? 1 : 0);
            ens160.setOperatingMode(ENS16X_OPERATING_MODE_IDLE);
            delay(50);
            ens160.setOperatingMode(ENS16X_OPERATING_MODE_STANDARD);
            delay(50);

            // Re-read status to confirm
            ens160.read(ENS16X_REGISTER_ADDRESS_DEVICE_STATUS, &devStatus, 1);
            log_i("ENS160 started. New Status=0x%02X (STATAS=%d, Validity=%u)",
                  devStatus, (devStatus & ENS16X_DEVICE_STATUS_ACTIVE) ? 1 : 0, (devStatus >> 2) & 0x03);
        }
    } else {
        log_e("Failed to detect ENS160 sensor at both 0x53 and 0x52!");
    }

    return (ahtInitialized || ensInitialized);
}

SensorData readSensors() {
    SensorData data;

    // 1. Read AHT21 First
    if (ahtInitialized) {
        sensors_event_t humidityEvent, tempEvent;
        if (aht.getEvent(&humidityEvent, &tempEvent)) {
            data.temperatureC = tempEvent.temperature;
            data.temperatureF = (data.temperatureC * 1.8f) + 32.0f;
            data.humidityPercent = humidityEvent.relative_humidity;
            data.ahtSuccess = true;
            log_i("AHT21: Temp=%.1f C, Humidity=%.1f %%", data.temperatureC, data.humidityPercent);
        } else {
            log_w("Failed to read data event from AHT21");
        }
    }

    // 2. Read ENS160 Gas Telemetry
    if (ensInitialized) {
        // Poll for new conversion data (up to 1200ms timeout)
        bool hasData = false;
        unsigned long tStart = millis();
        while ((millis() - tStart) < 1200) {
            if (ens160.update() == RESULT_OK && ens160.hasNewData()) {
                hasData = true;
                break;
            }
            delay(50);
        }

        // Guaranteed register read: Always ensure dataBuffer is populated from DATA_AQI (0x21)
        if (!hasData) {
            if (ens160.read(ENS16X_REGISTER_ADDRESS_DATA_AQI, ens160.getDataRaw(), ENS16X_BUFFER_INFO_DATA_SIZE) == RESULT_OK) {
                uint8_t devStatus = 0;
                ens160.read(ENS16X_REGISTER_ADDRESS_DEVICE_STATUS, &devStatus, 1);
                ens160.deviceStatus = devStatus;
                hasData = true;
            }
        }

        if (hasData) {
            uint8_t devStatus = ens160.getDeviceStatus();
            uint8_t validity = (devStatus >> 2) & 0x03;
            data.ensValidity = validity;

            uint8_t aqi = (uint8_t)ens160.getAirQualityIndex_UBA();
            if (aqi < 1) aqi = 1;
            if (aqi > 5) aqi = 5;
            data.aqiUba = aqi;

            data.tvocPpb = ens160.getTvoc();
            data.eco2Ppm = ens160.getEco2();
            data.ensSuccess = true;
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

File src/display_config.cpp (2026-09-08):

#include "display_config.h"

// Instantiate the global display object using the pins defined in config.h
GxEPD2_DISPLAY_CLASS display(GxEPD2_DRIVER_CLASS(EPD_CS_PIN, EPD_DC_PIN, EPD_RST_PIN, EPD_BUSY_PIN));

#include <driver/gpio.h>

// GxEPD2_EPD explicitly lists 'friend class GDEW075T7_OTP;' in GxEPD2_EPD_friends.h.
// We use this friend declaration to safely suppress the hardware RST pulse on partial-refresh
// wakeups so the controller SRAM (previous frame buffer) is NOT wiped when waking from deep sleep.
class GDEW075T7_OTP {
public:
    static void setRstPin(GxEPD2_EPD& epd, int16_t pin) {
        epd._rst = pin;
    }
};

void displayInitHardware(bool initial) {
    #if defined(EPD_PWR_PIN) && (EPD_PWR_PIN >= 0)
    // Release hold latch if waking from deep sleep, and ensure power is HIGH
    gpio_hold_dis((gpio_num_t)EPD_PWR_PIN);
    pinMode(EPD_PWR_PIN, OUTPUT);
    digitalWrite(EPD_PWR_PIN, HIGH);
    if (initial) {
        delay(15); // Allow onboard power rail and charge pump to stabilize on initial cold boot
    }
    #endif

    #if defined(EPD_RST_PIN) && (EPD_RST_PIN >= 0)
    gpio_hold_dis((gpio_num_t)EPD_RST_PIN);
    pinMode(EPD_RST_PIN, OUTPUT);
    digitalWrite(EPD_RST_PIN, HIGH);
    #endif

    #if defined(EPD_CS_PIN) && (EPD_CS_PIN >= 0)
    gpio_hold_dis((gpio_num_t)EPD_CS_PIN);
    pinMode(EPD_CS_PIN, OUTPUT);
    digitalWrite(EPD_CS_PIN, HIGH);
    #endif

    // Explicitly configure hardware SPI pins for FireBeetle 2 ESP32-E
    SPI.begin(EPD_SCK_PIN, -1, EPD_MOSI_PIN, EPD_CS_PIN);

    // Initialize SPI and display with serial diagnostic output
    // initial = true on first boot or periodic full anti-ghosting refresh
    // initial = false on differential partial refresh cycles (preserves controller SRAM)
    if (!initial && (EPD_RST_PIN >= 0)) {
        // Suppress hardware reset pulse during init so controller SRAM is retained
        GDEW075T7_OTP::setRstPin(display.epd2, -1);
        display.init(115200, false, 10, false);
        GDEW075T7_OTP::setRstPin(display.epd2, EPD_RST_PIN);
    } else {
        display.init(115200, initial, 10, false);
    }

    display.setRotation(0); // 0 = standard landscape (800x480)
    display.setTextColor(GxEPD_BLACK);

    #if defined(EPD_PWR_PIN) && (EPD_PWR_PIN >= 0)
    // Re-assert PWR pin to ensure SPI.begin() didn't alter its mode
    pinMode(EPD_PWR_PIN, OUTPUT);
    digitalWrite(EPD_PWR_PIN, HIGH);
    #endif
}

void displayPowerOff() {
    // Power off high-voltage driving circuits on the panel
    display.powerOff();

    #if defined(EPD_PWR_PIN) && (EPD_PWR_PIN >= 0)
    // Keep 3.3V power to the HAT controller logic across deep sleep so internal
    // SRAM preserves the previous frame buffer. Differential refresh relies on this!
    pinMode(EPD_PWR_PIN, OUTPUT);
    digitalWrite(EPD_PWR_PIN, HIGH);
    gpio_hold_en((gpio_num_t)EPD_PWR_PIN);
    #endif

    #if defined(EPD_RST_PIN) && (EPD_RST_PIN >= 0)
    // Hold RST HIGH across deep sleep so the controller is never glitched or reset
    pinMode(EPD_RST_PIN, OUTPUT);
    digitalWrite(EPD_RST_PIN, HIGH);
    gpio_hold_en((gpio_num_t)EPD_RST_PIN);
    #endif

    #if defined(EPD_CS_PIN) && (EPD_CS_PIN >= 0)
    // Hold CS HIGH (inactive) across deep sleep
    pinMode(EPD_CS_PIN, OUTPUT);
    digitalWrite(EPD_CS_PIN, HIGH);
    gpio_hold_en((gpio_num_t)EPD_CS_PIN);
    #endif

    gpio_deep_sleep_hold_en();
}

void displayHibernate() {
    display.hibernate();
    #if defined(EPD_PWR_PIN) && (EPD_PWR_PIN >= 0)
    digitalWrite(EPD_PWR_PIN, LOW);
    pinMode(EPD_PWR_PIN, INPUT);
    #endif
}

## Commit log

2026-09-05 fix: update wiring documentation and config comments to clarify EPD_BUSY_PIN selection and add local port configuration
    [config.h]
2026-09-05 feat: add support for Waveshare e-Paper HAT power control and implement software-timed refresh cycles
2026-09-05 feat: implement dual-partition OTA update system with browser-based dashboard and firmware management
    [partitions_16MB_ota.csv]
2026-09-06 Add 3D printable snap-fit desk enclosure CAD models and STLs
    [eink_clock_enclosure.scad, front_bezel.stl, rear_stand.stl]
2026-09-07 Release v1.0.5
    [Front Panel-BodyPocket011.3mf, Front Panel.FCStd]
2026-09-08 feat: update front panel design, fix README links, and add version check to release script
    [Front Panel.3mf, Front Panel.FCStd]
2026-09-08 fix(ui): improve battery text spacing and dynamic right alignment
2026-09-08 fix(sensors): ensure ENS160 STATAS active bit is checked before skipping start
    [sensors.cpp]
